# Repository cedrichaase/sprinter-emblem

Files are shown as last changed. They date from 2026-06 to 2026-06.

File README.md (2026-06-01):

# Sprinter / Crafter Emblem

A parametric OpenSCAD library for creating custom rear emblems for the **Mercedes-Benz Sprinter** and **VW Crafter**. Bring your own SVG logo and get a print-ready emblem that fits the stock mounting points.

## What it produces

A ~120mm circular emblem with:
- a domed, slightly convex face
- your logo raised on that curved surface
- a clean border ring
- a separate mounting washer

Designed to be printed in PETG.

## Requirements

- [OpenSCAD](https://openscad.org/) (2021.01 or later recommended for SVG import support)
- A slicer such as PrusaSlicer or BambuStudio

## Usage

1. Place your SVG logo in the project directory.
2. In `emblem.scad`, replace the `logo2()` call with an SVG import:

```scad
module logo() {
    intersection() {
        translate([0, 0, 2]) dome();
        linear_extrude(height=15) scale(1/3) import(file="./your-logo.svg", center=true);
    }
}
```

3. Preview and export:

```bash
openscad emblem.scad                # live preview
openscad -o emblem.stl emblem.scad  # export for slicing
openscad -o washer.stl washer.scad  # export mounting washer
```

4. Slice and print both parts in PETG.

## SVG tips

- Center your artwork at the origin in your vector editor before exporting.
- The emblem face is 120mm in diameter; design at roughly 360mm wide and let the `scale(1/3)` in the import handle the resize, or adjust the scale factor to taste.
- Simple, bold shapes work best — fine detail gets lost at this scale.

## Files

| File | Description |
|---|---|
| `emblem.scad` | Main emblem model |
| `washer.scad` | Mounting washer (r=12mm / r=4.2mm) |
| `pacifik_mers.stl` | Base star geometry (source asset) |
| `mountain-logo.svg` | Example SVG input |

## Example

`mountain-logo.svg` is included as a reference — a simple mountain/landscape design that demonstrates how an SVG is mapped onto the domed surface.

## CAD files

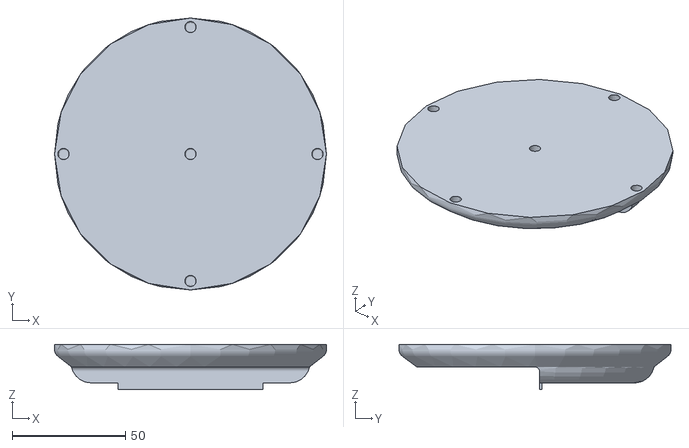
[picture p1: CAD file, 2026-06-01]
pacifik_mers.stl
120.0 x 120.0 x 20.0

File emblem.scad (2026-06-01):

$fn=200;

svg_file        = "./peace.svg";
emblem_d        = 120;
protrude        = 2;      // mm logo protrudes above dome surface

// potrace outputs SVG with pt units matching the input BMP pixel count
// peace.svg: 1000pt → 1000*(25.4/72) = 352.78mm in OpenSCAD
svg_mm          = 1000 * (25.4 / 72);
// Peace symbol outer ring is at r=430 in a 1000px BMP → 430/500 of SVG half-width.
// Scale up so the outer ring lands exactly at the emblem edge.
logo_d          = emblem_d * (500.0 / 430.0);
logo_scale      = logo_d / svg_mm;

sphere_z_factor = 1/10;

module base() {
    import("./pacifik_mers.stl");
    translate([0, 0, 3]) cylinder(h=2, d=emblem_d);
}

module dome(d=emblem_d, z_factor=sphere_z_factor) {
    sphere_height = z_factor * d;
    translate([0, 0, sphere_height/2 - 2.5]) difference() {
        scale([1, 1, z_factor]) sphere(d=d);
        translate([0, 0, -sphere_height/2]) cylinder(h=sphere_height/2, d=d);
    }
}

module logo_extrude(h=20) {
    rotate([0, 0, 90])
    scale([logo_scale, logo_scale, 1])
        translate([-svg_mm/2, -svg_mm/2, 0])
            linear_extrude(height=h)
                import(file=svg_file);
}

module emblem() {
    base();
    union() {
        dome();
        // Uniform protrusion: outer shell is the same dome shifted up by `protrude` mm,
        // so the gap between inner and outer surface is exactly `protrude` everywhere.
        intersection() {
            logo_extrude(h=20);
            difference() {
                translate([0, 0, protrude]) dome();
                dome();
            }
        }
    }
}

emblem();

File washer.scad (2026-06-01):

$fn=100;

difference() {
    cylinder(h=2, r=12);
    cylinder(h=2, r=4.2);
}

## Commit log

2026-06-01 Initial commit: OpenSCAD emblem library for Sprinter/Crafter rear emblems
    Library for generating custom Mercedes-Benz Sprinter / VW Crafter rear
    emblems from SVG logos. Includes base geometry (pacifik_mers.stl), emblem
    and washer models, and mountain-logo.svg as an example SVG input.
    [emblem.scad, pacifik_mers.stl, washer.scad]
2026-06-01 Fix SVG centering and add negative-relief logo mode
    Correct the pt→mm unit conversion for potrace SVG imports: 250pt = 88.2mm
    in OpenSCAD space, so the center offset and scale factor were wrong.
    Replace the intersection-based logo with a difference() so the design is
    carved into the dome as a negative relief. Also ignore rendered PNGs.
    [emblem.scad]
2026-06-01 Switch FVF emblem to uniform positive relief
    - Reference fvf-logo.svg; SVG border replaces the SCAD border() module
    - Logo protrudes 2mm above dome surface uniformly (translated dome shell
    instead of scaled, so gap is constant everywhere rather than tapering)
    - Rotate logo 90° to align with base geometry
    - logo_d = emblem_d so SVG fills the full emblem face
    [emblem.scad]
2026-06-01 Add peace symbol emblem
    - Rasterise peace symbol with PIL, trace to SVG with potrace
    - Scale logo so outer ring is flush with emblem edge (500/430 factor)
    - 90° rotation to align with base geometry
    - svg_mm updated for 1000pt potrace output
    [emblem.scad]
